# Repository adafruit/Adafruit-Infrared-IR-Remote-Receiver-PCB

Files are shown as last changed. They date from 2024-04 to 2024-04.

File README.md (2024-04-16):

## Adafruit Infrared IR Remote Receiver - STEMMA JST PH 2mm PCB

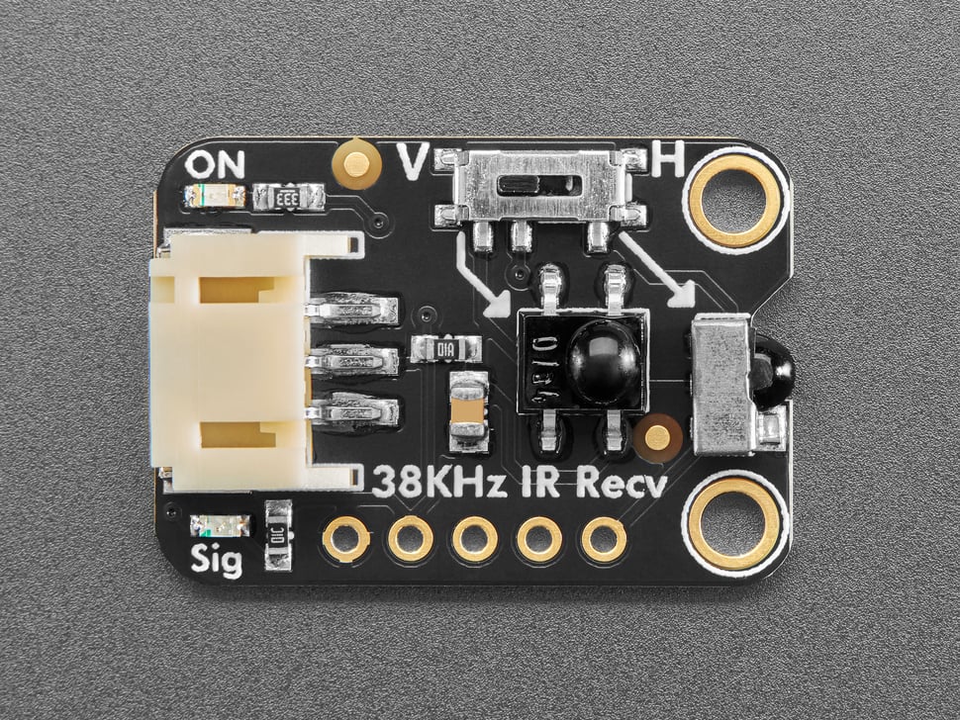
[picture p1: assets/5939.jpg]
<a href="http://www.adafruit.com/products/5939"><br/>
Click here to purchase one from the Adafruit shop</a>

PCB files for the Adafruit Infrared IR Remote Receiver - STEMMA JST PH 2mm. 

Format is EagleCAD schematic and board layout
* https://www.adafruit.com/product/5939

### Description

A year ago we designed a high-current-output Infrared Transmitter STEMMA which makes it easy to create high-powered IR LED blasters. Now we've sat down to design the other side, the super sensitive wide-range Adafruit Infrared IR Remote Receiver with two selectable IR receiver chips.

We found plenty of 38KHz receiver sensors that would work nicely on this breakout board - but when it came to choosing one that was vertical or horizontal we just couldn't make up our mind...so why not both? We've placed one on the end and one in the middle, and a slide switch to select which one you want to read signal from. We can't just tie the outputs together because they'd 'fight' each other and give incoherent output - but if you're willing to solder two wires, it's possible to read each one independently thanks to labelled breakout pads.

Usage is simple: Power the board by connecting V+ and ground to 3~5VDC, point a 38KHz remote control at the sensors and press some buttons. The demodulated IR envelope is piped out the Signal pin into your microcontroller which will then need to decode it. To make usage really easy, we have a green 'power good' LED and a red 'signal' LED. When IR remote signals are read by the onboard sensors, the red LED will blink to let you know.

This board will work nicely for a variety of IR remote receiving projects, and with mounting holes and a cable, a lot easier to mount in enclosures and on devices. Using a 2mm pitch STEMMA JST PH cable with headers or alligator clips on the end, you can easily wire this board without any soldering.

Note that this board is specifically for receiving 38KHz IR remote control signals - it isn't going to work for proximity/distance sensing or other frequency signals. The signal must be read by a microcontroller that has pulse-input reading capabilities - basically just check that it supports common IR Receiver connectivity and decoding. Sometimes you need to use special code or pins.

Each STEMMA board is a fully assembled and tested PCB but no cable. No soldering is required to use it, but you will need to pick up a 2mm pitch, 3-pin STEMMA JST PH cable. Alternatively, if you do want to solder, there's a 0.1" spaced header for power/ground/signal.

### License

Adafruit invests time and resources providing this open source design, please support Adafruit and open-source hardware by purchasing products from [Adafruit](https://www.adafruit.com)!

Designed by Limor Fried/Ladyada for Adafruit Industries.

Creative Commons Attribution/Share-Alike, all text above must be included in any redistribution. 
See license.txt for additional details.

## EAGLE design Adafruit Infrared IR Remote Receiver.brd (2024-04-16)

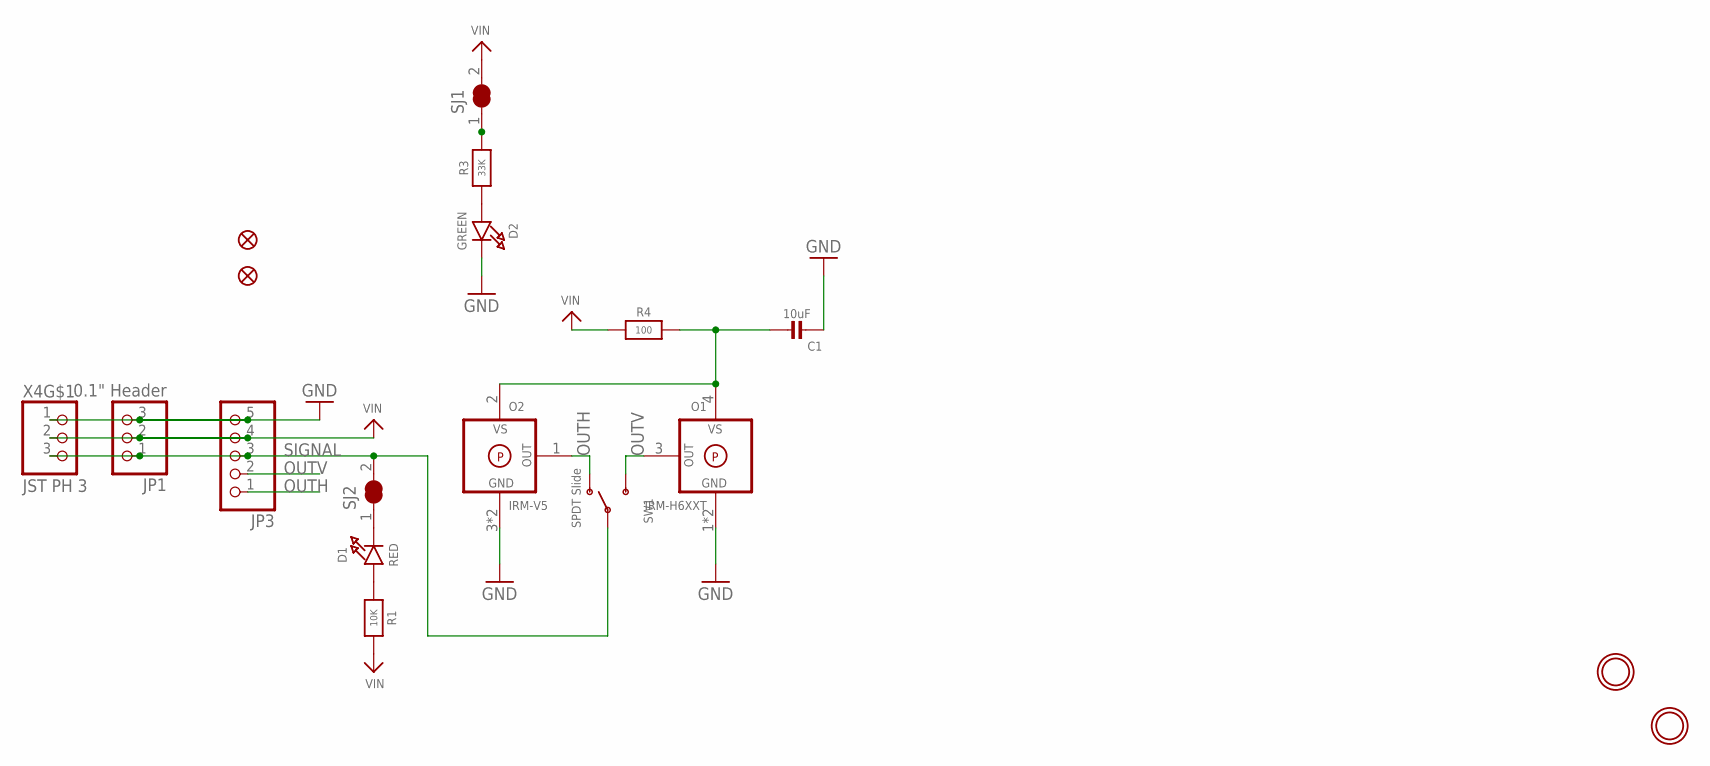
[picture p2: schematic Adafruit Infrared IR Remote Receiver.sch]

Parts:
C1: 10uF; 0805-NO
D1: RED; CHIPLED_0603_NOOUTLINE
D2: GREEN; CHIPLED_0603_NOOUTLINE
FID2, FID3: FIDUCIAL_1MM
JP1: 0.1" Header; 1X03_OVAL
JP3: HEADER-1X570MIL; 1X05_ROUND_70
O1: IRM-H6XXT
O2: IRM-V5
R1: 10K; 0603-NO
R3: 33K; 0603-NO
R4: 100; 0603-NO
SJ1, SJ2: SOLDERJUMPER_CLOSED; SOLDERJUMPER_CLOSEDWIRE
SW1: SPDT Slide; SPDT_SMT_SSSS811101
U$1, U$8: MOUNTINGHOLE2.5; MOUNTINGHOLE_2.5_PLATED
X4: JST PH 3; JSTPH3

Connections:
GND: C1.2, D2.C, JP1.3, JP3.5, O1.1 (GND), O1.2 (GND), O2.3 (GND), O2.MT (GND), X4.1
unnamed: R3.2, SJ1.1
unnamed: D1.A, R1.1
unnamed: D1.C, SJ2.1
unnamed: C1.1, O1.4 (VS), O2.2 (VS), R4.2
unnamed: D2.A, R3.1
OUTH: JP3.1, O2.1 (OUT), SW1.A (O)
OUTV: JP3.2, O1.3 (OUT), SW1.C (S)
SIGNAL: JP1.1, JP3.3, SJ2.2, SW1.B, X4.3
VIN: JP1.2, JP3.4, R1.2, R4.1, SJ1.2, X4.2

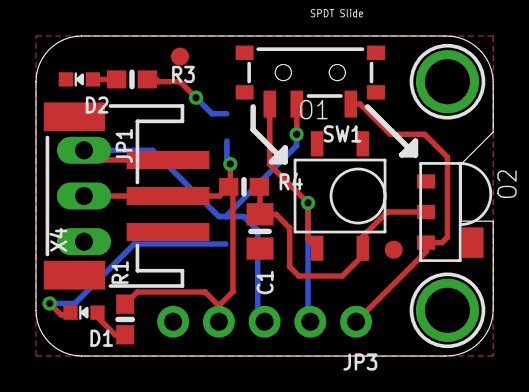
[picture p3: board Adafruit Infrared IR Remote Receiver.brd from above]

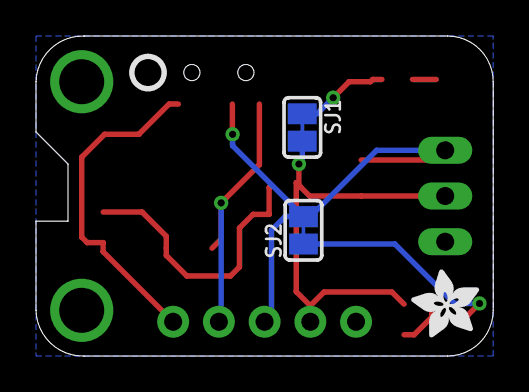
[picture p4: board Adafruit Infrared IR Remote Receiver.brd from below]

Board: 2 copper layers, 25.4 x 17.8 mm, 37 parts (16 on the bottom side), 10 nets.

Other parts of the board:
PLABEL0: PLABEL0
PLABEL1: PLABEL1
PLABEL2, PLABEL14: PLABEL14
PLABEL3, PLABEL13: PLABEL13
PLABEL5: PLABEL5
PLABEL15: PLABEL15
PLABEL16: PLABEL16
PLABEL17: PLABEL17
PLABEL18: PLABEL18
PLABEL19: PLABEL19
PLABEL20: PLABEL20
PLABEL21: PLABEL21
PLABEL22: PLABEL22
PLABEL23: PLABEL23
PLABEL24: PLABEL24
U$5: PCBFEAT-REV-040
U$10: ADAFRUIT_3.5MM

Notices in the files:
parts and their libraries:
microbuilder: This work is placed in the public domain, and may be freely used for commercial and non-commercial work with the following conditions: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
